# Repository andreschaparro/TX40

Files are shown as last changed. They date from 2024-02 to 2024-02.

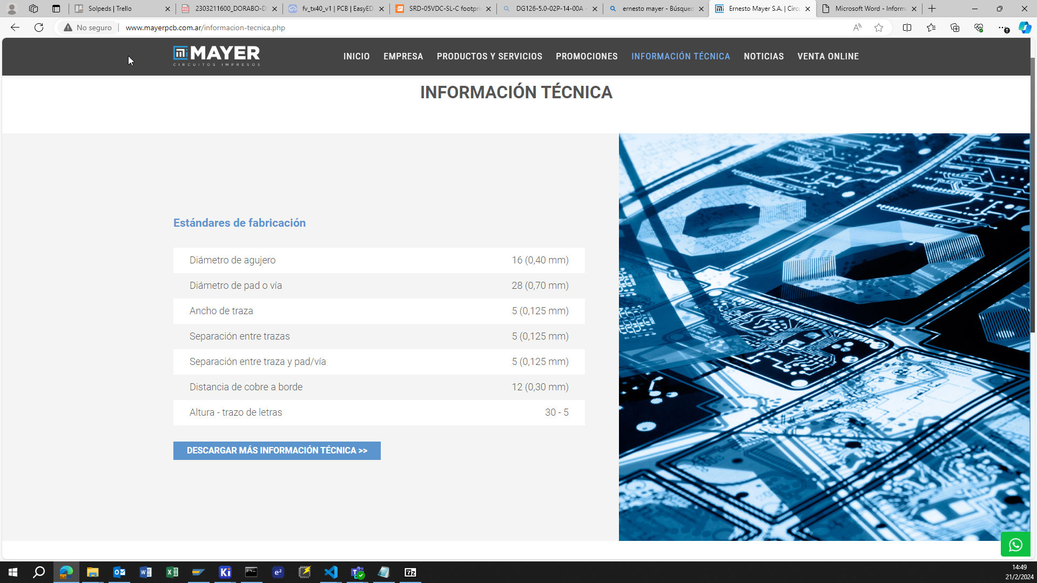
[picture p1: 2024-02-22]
doc/otras especificaciones.png

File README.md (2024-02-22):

# PCB TX40

Este repositorio, contiene el diseño en Kicad de una placa para aislar las entradas de un controlador *BRAHMA*.

La entradas, cierran 5V en el PCB, y activan o desactivan 2 reles que se accionaran sobre el controlador original.

Esto es necesario, para que los sensores trabajen con niveles de tension segura.

Originalmente, el controlador tiene una fuente switching no aislada galvanicamente (LNK304) y produce que las entradas del mismo no tengan tensiones de trabajo seguras.

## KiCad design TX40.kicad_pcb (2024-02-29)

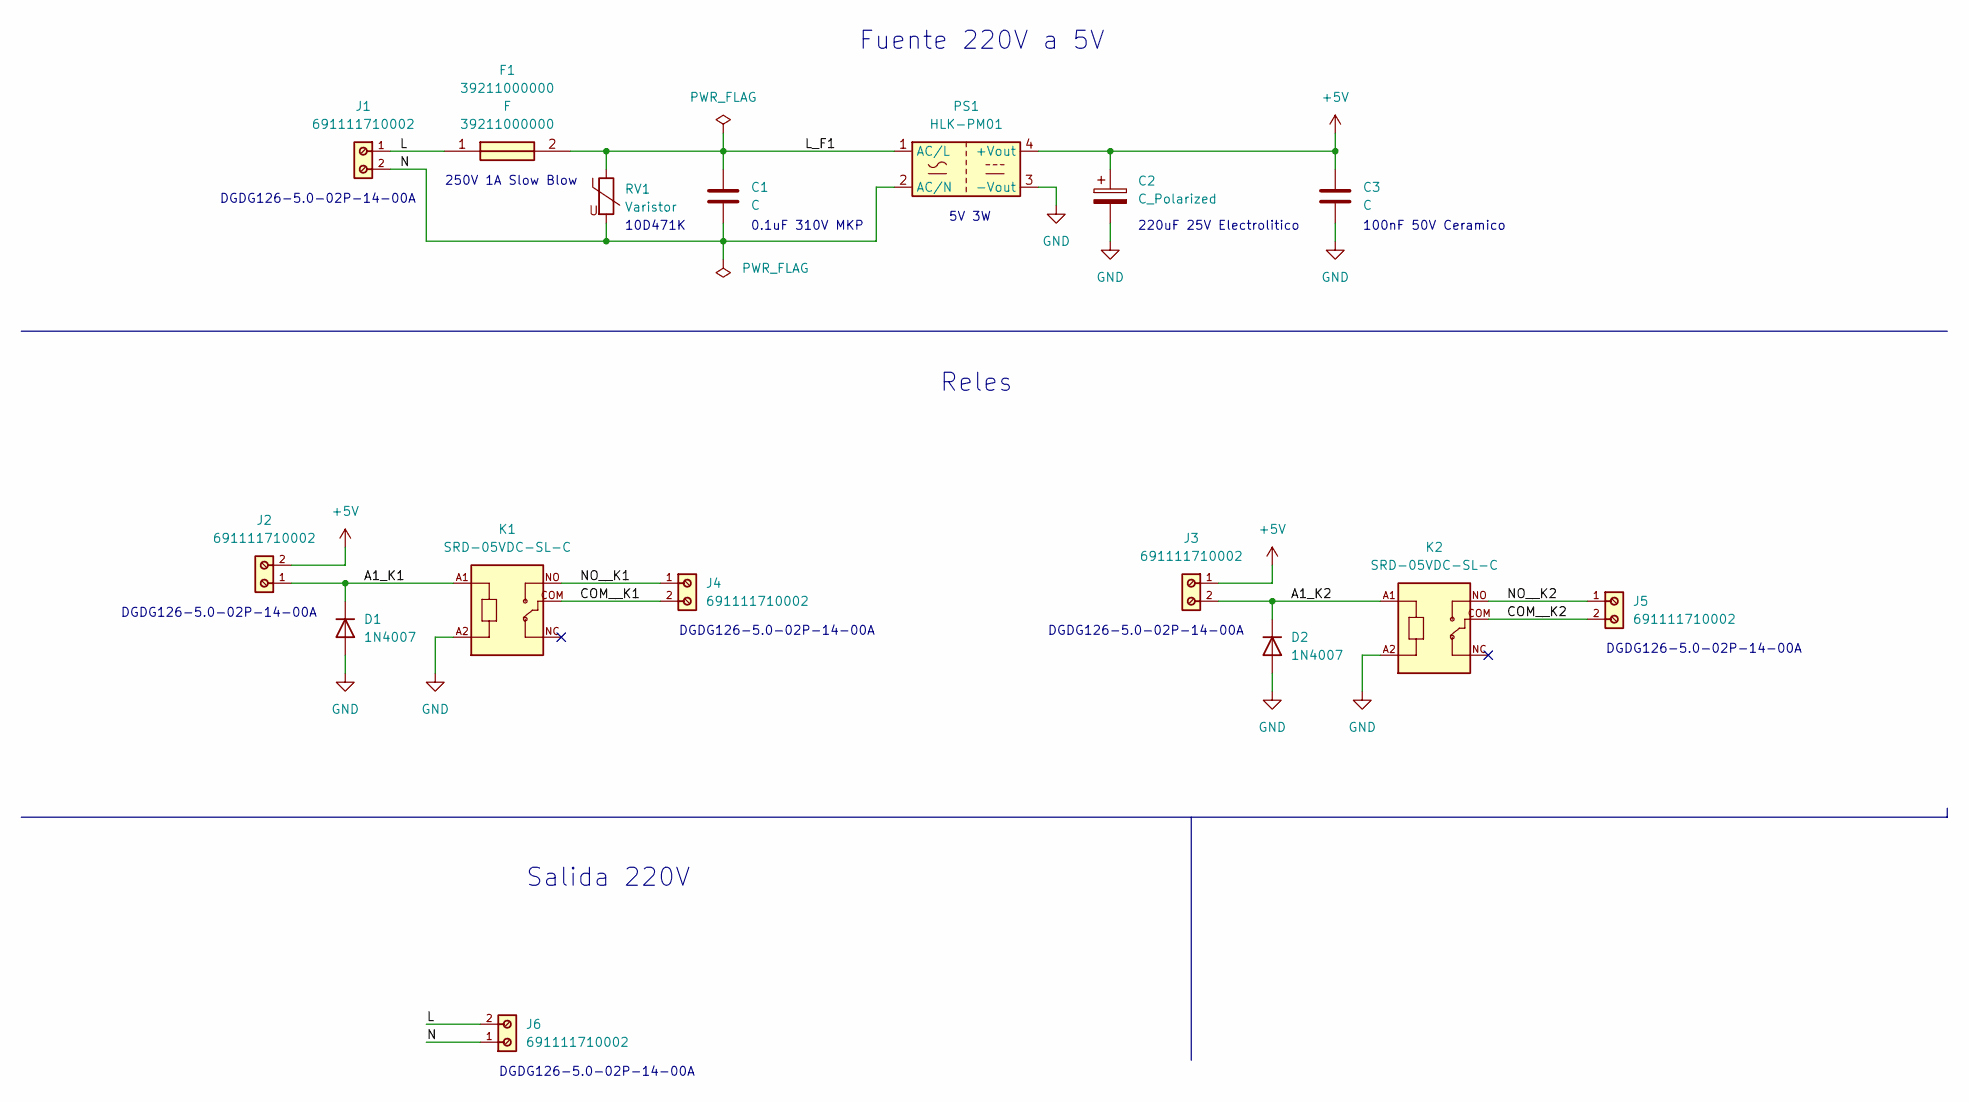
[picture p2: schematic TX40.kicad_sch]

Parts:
C1: C; C_Rect_L13.0mm_W6.0mm_P10.00mm_FKS3_FKP3_MKS4
C2: C_Polarized; CP_Radial_D8.0mm_P3.50mm
C3: C; C_Disc_D5.0mm_W2.5mm_P2.50mm
D1, D2: 1N4007; D_DO-41_SOD81_P10.16mm_Horizontal
F1: 39211000000; Manufacturer_Part_Number 39211000000; Mouser Part Number 576-3921100000
J1, J2, J3, J4, J5, J6: 691111710002; PART-NUMBER 691111710002
K1, K2: SRD-05VDC-SL-C; RELAY_SRD-05VDC-SL-C
PS1: HLK-PM01; Converter_ACDC_HiLink_HLK-PMxx
RV1: Varistor; RV_Disc_D12mm_W5.4mm_P7.5mm

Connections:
+5V: C2.1, C3.1, J2.2, J3.1, PS1.4 (+Vout)
/A1_K1: D1.1 (K), J2.1, K1.A1
/A1_K2: D2.1 (K), J3.2, K2.A1
/COM__K1: J4.2, K1.COM
/COM__K2: J5.2, K2.COM
/L: F1.1, J1.1, J6.2
/L_F1: C1.1, F1.2, PS1.1 (AC/L), RV1.1
/N: C1.2, J1.2, J6.1, PS1.2 (AC/N), RV1.2
/NO__K1: J4.1, K1.NO
/NO__K2: J5.1, K2.NO
GND: C2.2, C3.2, D1.2 (A), D2.2 (A), K1.A2, K2.A2, PS1.3 (-Vout)

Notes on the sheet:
Salida 220V
10D471K
250V 1A Slow Blow
220uF 25V Electrolitico
100nF 50V Ceramico
0.1uF 310V MKP
5V 3W
DGDG126-5.0-02P-14-00A
Reles
Fuente 220V a 5V

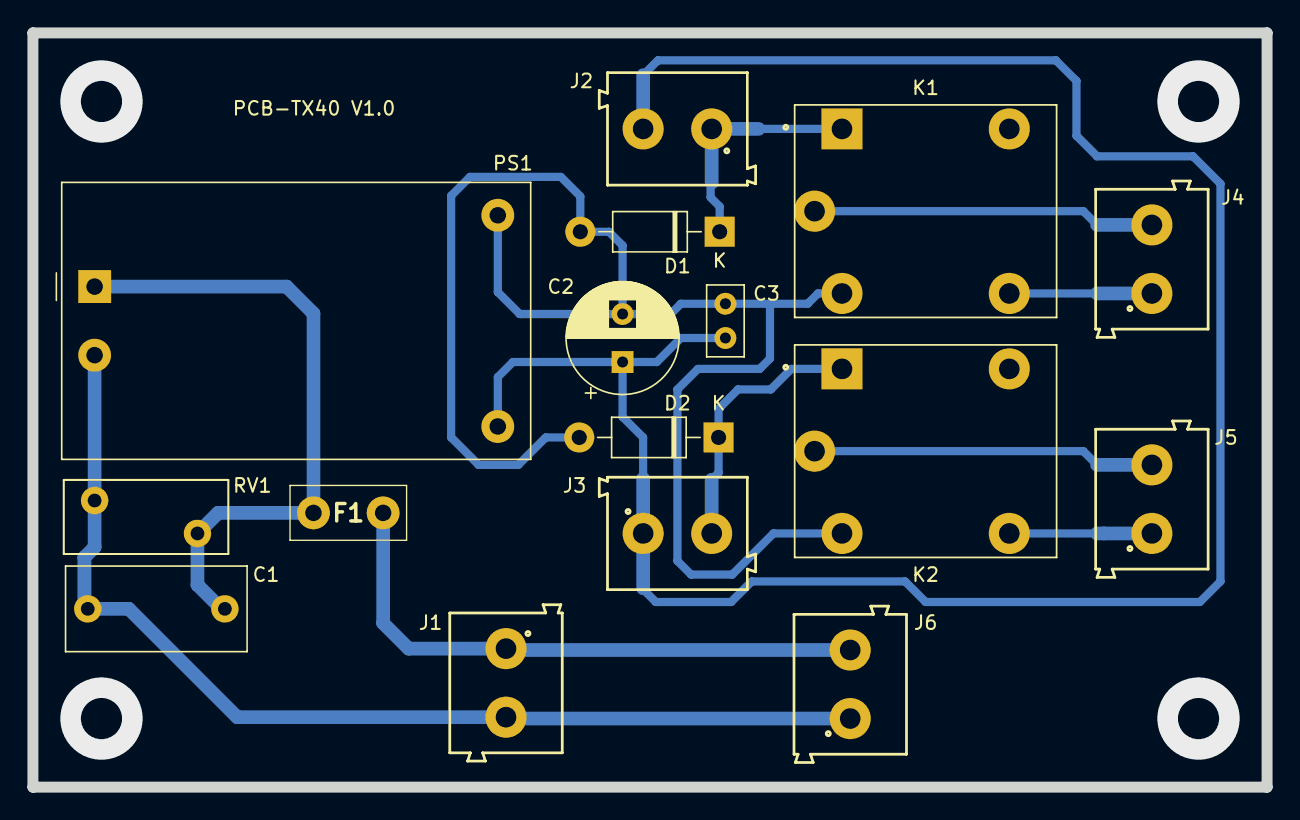
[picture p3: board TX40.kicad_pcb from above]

Board: 2 copper layers, 90.0 x 55.0 mm, 16 parts (0 on the bottom side), 11 nets.

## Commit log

2024-02-22 Commit Inicial
    [TX40.kicad_pcb, TX40.kicad_sch]
2024-02-29 Cambio a placa de 55x90
    [TX40.kicad_pcb, TX40.kicad_sch]
